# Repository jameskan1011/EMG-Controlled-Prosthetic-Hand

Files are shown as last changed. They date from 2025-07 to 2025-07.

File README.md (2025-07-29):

# EMG-Controlled Prosthetic Hand

This project features a **wireless prosthetic hand system** powered by EMG signal control.  
A wearable EMG device captures muscle activity and translates it into movement commands for a robotic hand.  
Force sensors on the robotic fingers detect contact pressure and send feedback wirelessly to activate a **vibration motor** on the glove.  
All communication is handled efficiently via the **ESP-NOW protocol** for real-time response.

---

## 🖐️ Prosthetic Hand

<p align="center">
  Prosthetic Hand
</p>

---

## 🧤 EMG Sensor Device

<p align="center">
  EMG Sensor Glove Front
  &nbsp;&nbsp;&nbsp;
  EMG Sensor Glove Back
</p>

---

## 📽️ Demonstration

<p align="center">
  <video src="https://github.com/user-attachments/assets/7f13d15d-7b53-4090-8c28-4c555c97ecc5" autoplay loop muted playsinline width="100"></video>
</p>

**Grasping Objects using Pinch and Power Grip**

<p align="center">
  Grasp Demo
</p>

---

## 🧠 Features
<h3 align="center">Sensor Feedback</h3>
<p align="left"><em>
Soft TPU material is layered above the fingertip and force sensor, allowing analog pressure values to be read when compressed.
</em></p>
<p align="center">
  
  &nbsp;&nbsp;&nbsp;
  
</p>

<p align="left"><em>
Each of the five servos is responsible for controlling an individual finger on the prosthetic hand, enabling coordinated grasping movements.
</em></p>
<p align="center">
  
</p>

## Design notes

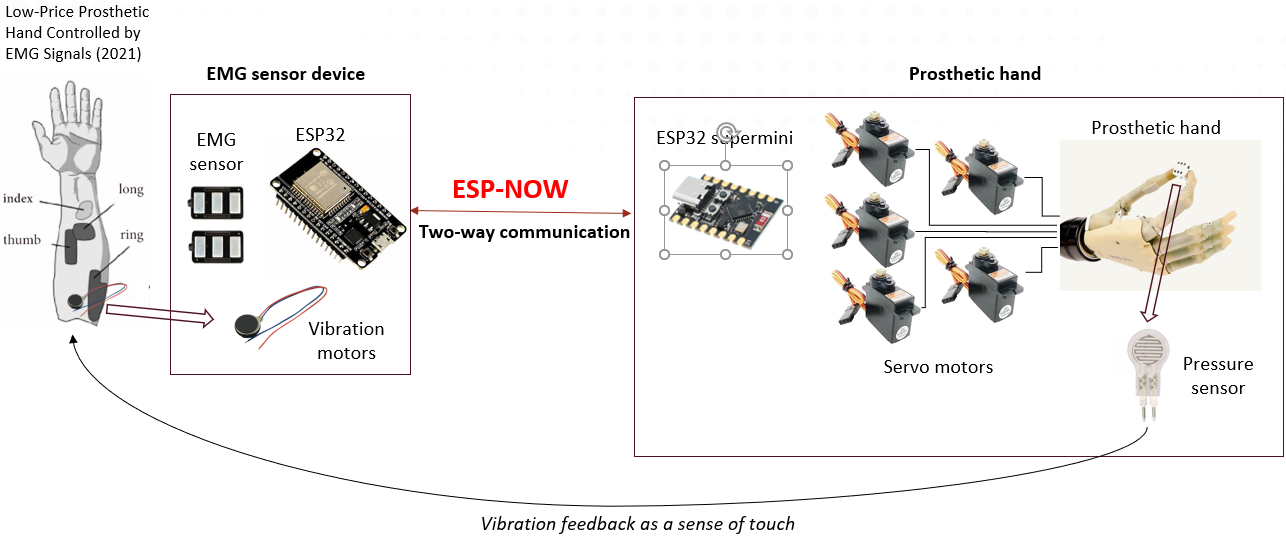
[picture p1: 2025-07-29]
Circuit/System.png

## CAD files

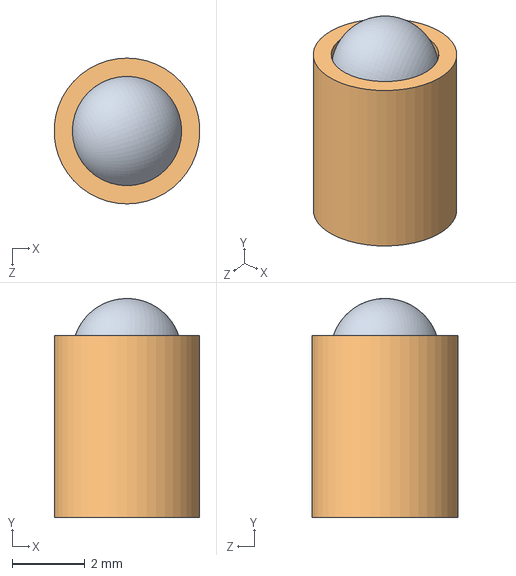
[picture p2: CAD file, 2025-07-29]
3D model/plunger/plunger.SLDASM
3.99 x 6.01 x 4.00 mm
bearing
socket

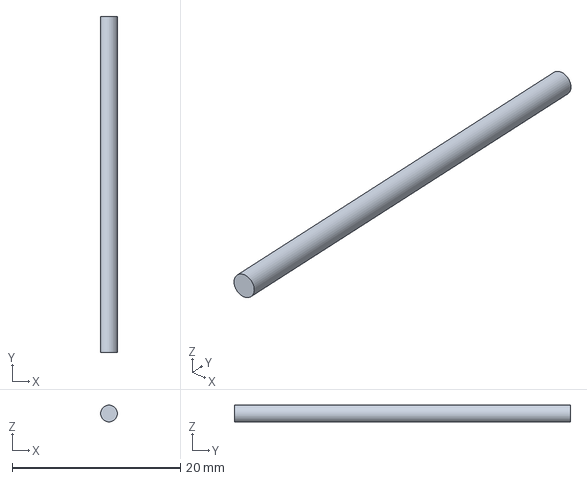
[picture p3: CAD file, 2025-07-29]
3D model/2mm joint.3MF
2.00 x 40.0 x 2.00 mm

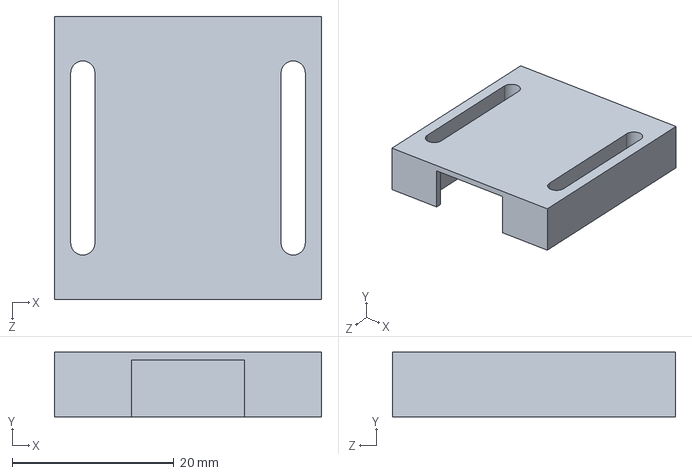
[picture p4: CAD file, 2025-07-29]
3D model/ESP32_enclosure/EMGsensor_cover.SLDPRT
33.0 x 8.00 x 35.0 mm

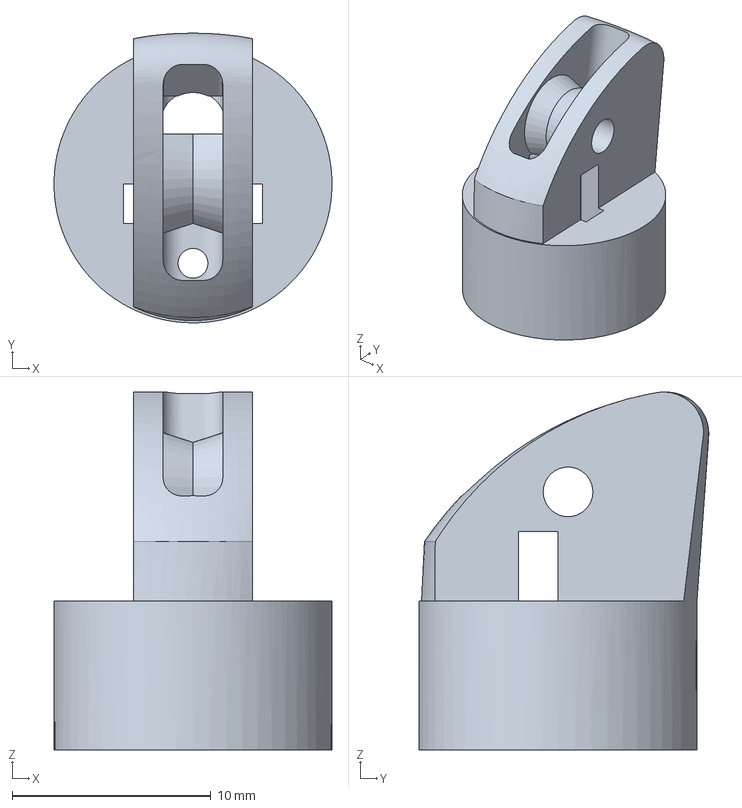
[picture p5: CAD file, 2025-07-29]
3D model/Index/bambu/index2_V4(reduce friction).3MF
14.0 x 14.6 x 18.0 mm

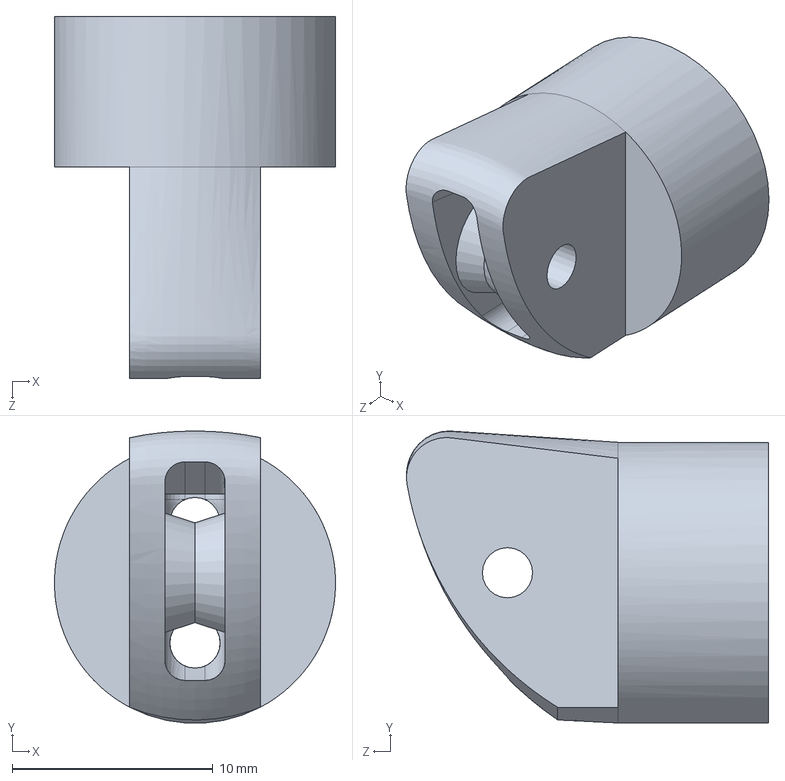
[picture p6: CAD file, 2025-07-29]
3D model/Index/index2.SLDPRT
14.0 x 14.5 x 18.0 mm

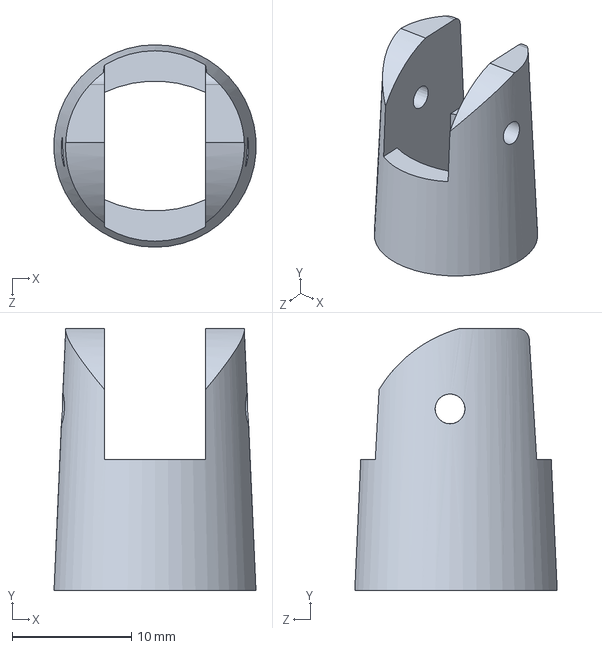
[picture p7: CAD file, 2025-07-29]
3D model/middle/middle3.SLDPRT
17.0 x 22.0 x 17.0 mm

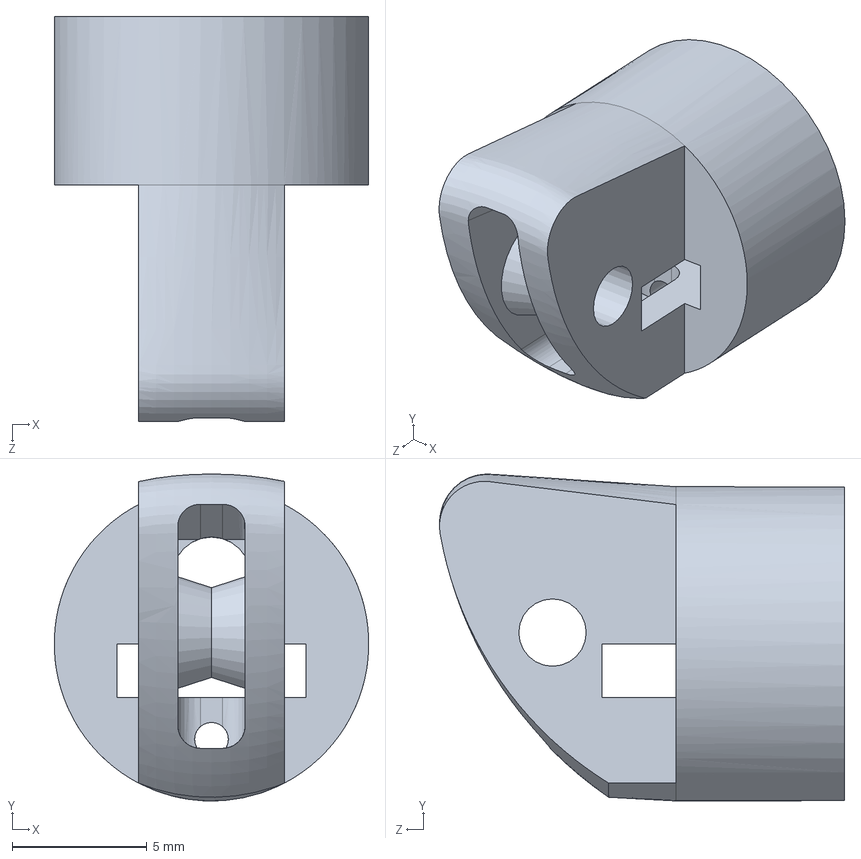
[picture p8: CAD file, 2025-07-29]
3D model/pinky/pinky2.SLDPRT
11.7 x 12.1 x 15.0 mm

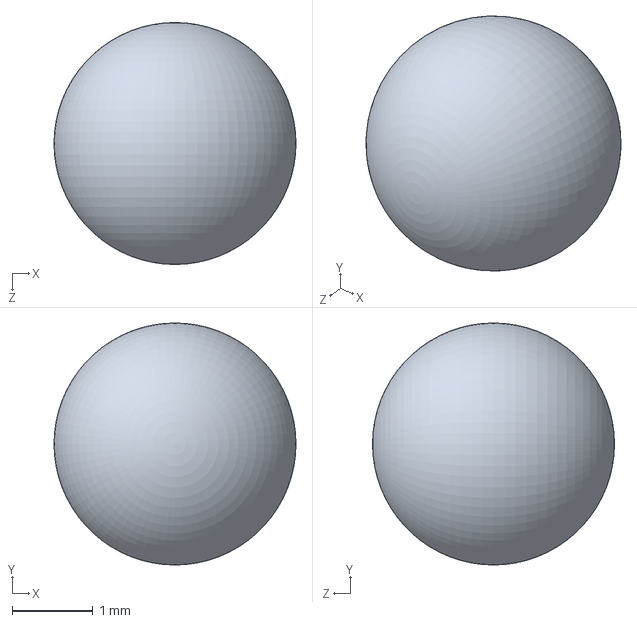
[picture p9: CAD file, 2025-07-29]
3D model/plunger/bearing.SLDPRT
3.00 x 3.00 x 3.00 mm

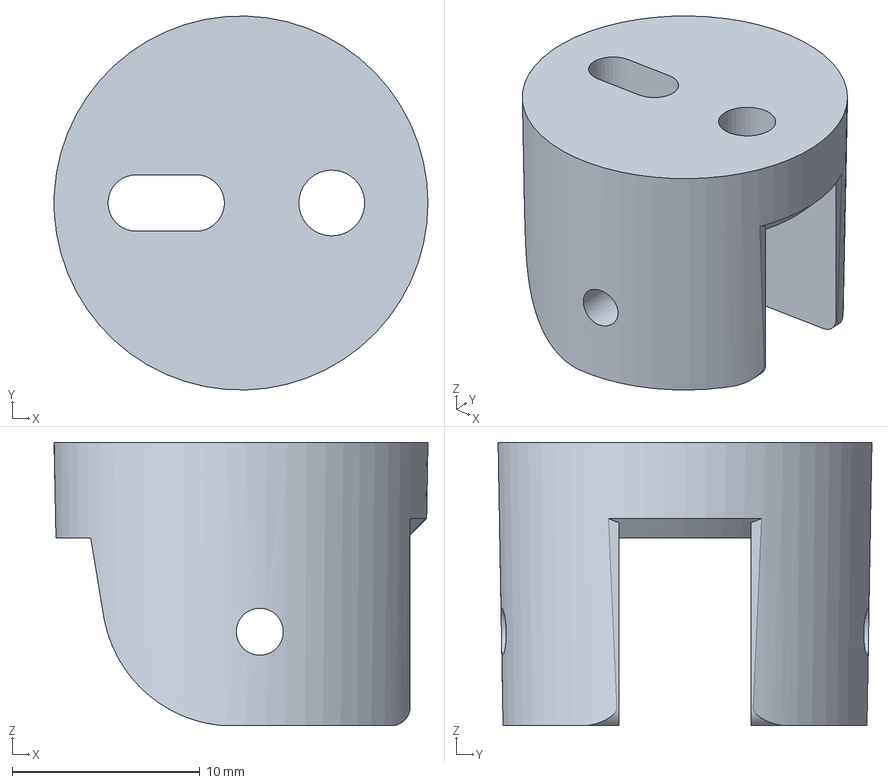
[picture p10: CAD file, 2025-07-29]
3D model/thumb/bambu/thump3.3MF
19.9 x 19.9 x 15.1 mm

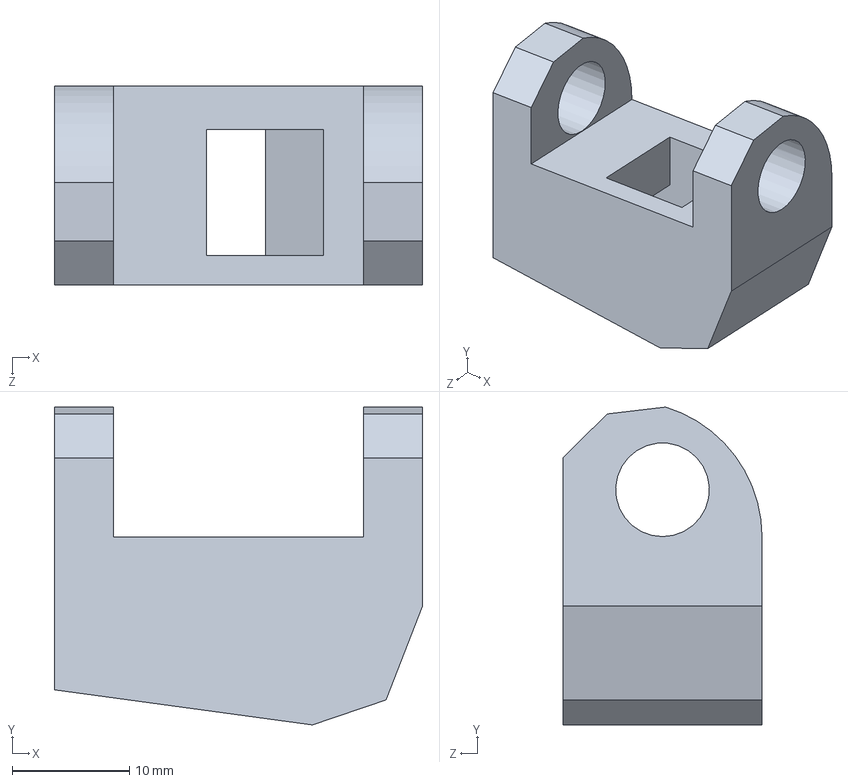
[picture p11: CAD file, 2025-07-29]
3D model/thumb/thump6_v2.SLDPRT
31.4 x 27.1 x 17.0 mm

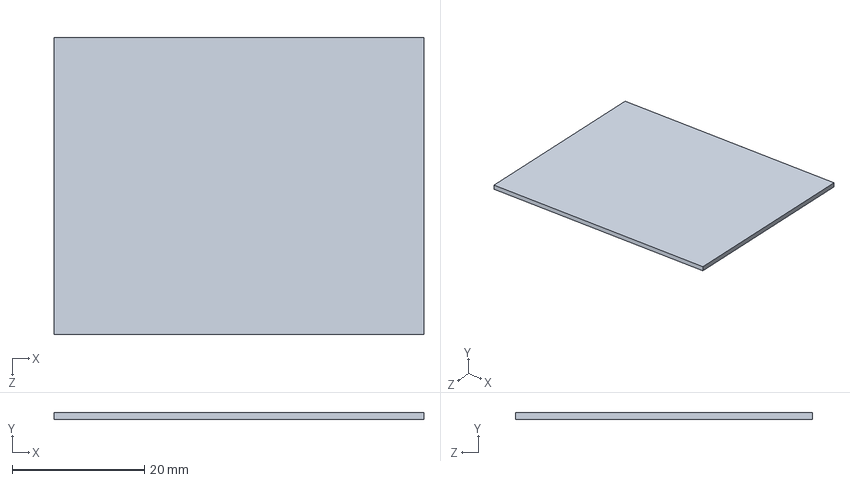
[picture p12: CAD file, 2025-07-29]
3D model/ESP32_enclosure/ESP32_enclosureLid.SLDPRT
56.0 x 1.00 x 45.0 mm

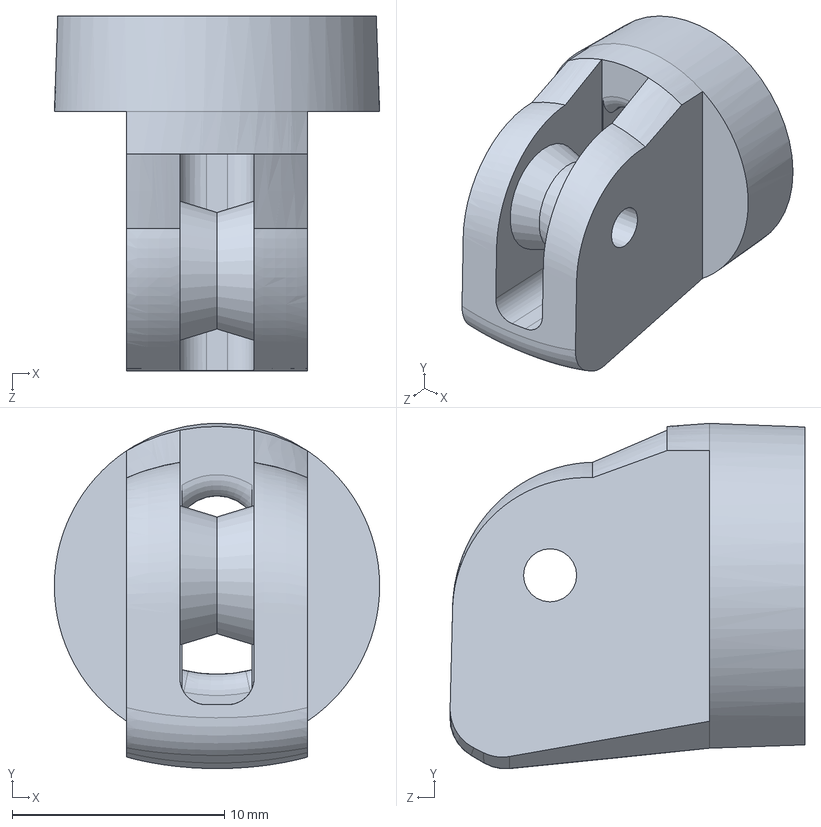
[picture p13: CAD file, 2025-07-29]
3D model/middle/middle5.SLDPRT
15.3 x 16.3 x 16.7 mm

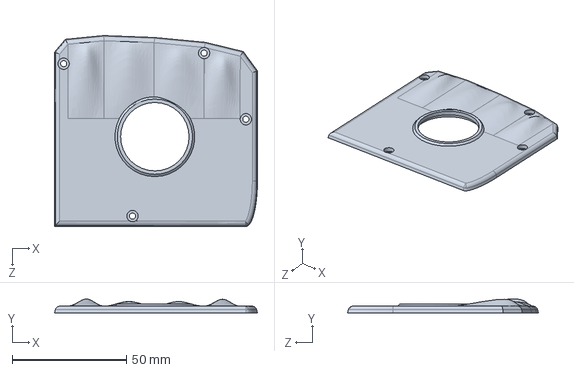
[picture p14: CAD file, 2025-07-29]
3D model/palm_bottom.SLDPRT
89.0 x 6.15 x 83.7 mm

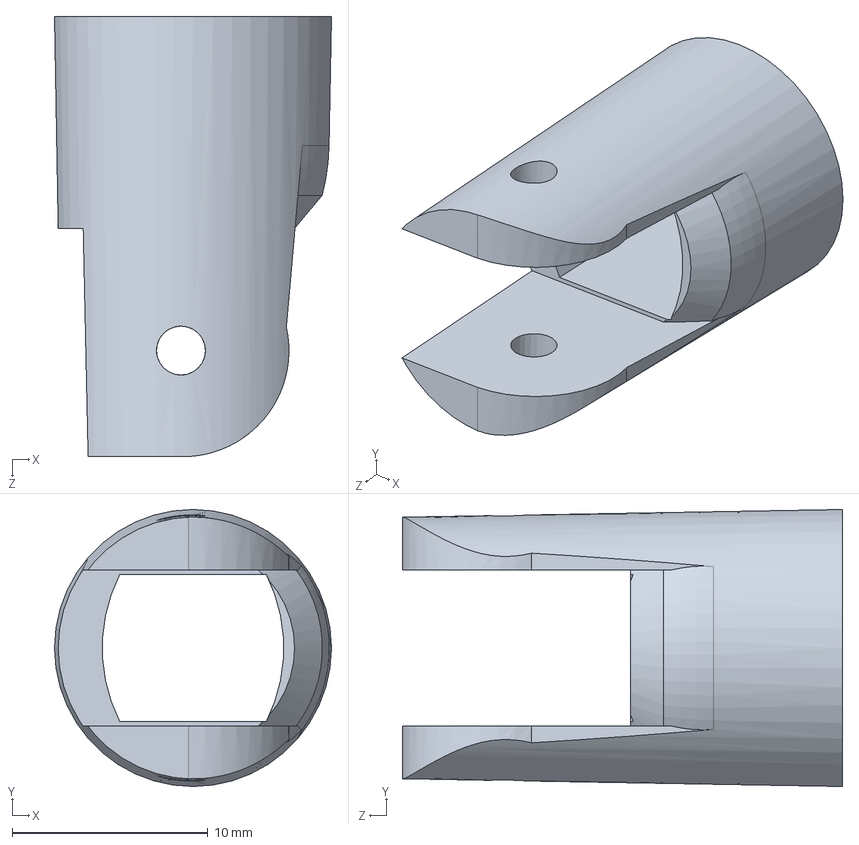
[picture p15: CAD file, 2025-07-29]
3D model/pinky/pinky4.SLDPRT
14.2 x 14.2 x 22.5 mm

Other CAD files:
3D model/Index/bambu/index2_V3.STEP
3D model/Index/index2_V4(reduce friction).SLDPRT
3D model/plunger/socket.SLDPRT
3D model/thumb/bambu/Thump1.3MF
3D model/2051_servo_tower-pro-sg90.pk2.SLDPRT
3D model/ESP32_enclosure/EMGsensor_cover.3MF
3D model/ESP32_enclosure/ESP32_enclosure.3MF
3D model/ESP32_enclosure/ESP32_enclosure.SLDPRT
3D model/ESP32_enclosure/ESP32_enclosureLid.3MF
3D model/Index/bambu/index1.3MF
3D model/Index/bambu/index1.gcode.3mf
3D model/Index/bambu/index1_TPU.3MF
3D model/Index/bambu/index1_TPU_V2.3MF
3D model/Index/bambu/index1_modifiled.3MF
3D model/Index/bambu/index1_modifiled.gcode.3mf
3D model/Index/bambu/index2.3MF
3D model/Index/bambu/index2_V2.3MF
3D model/Index/bambu/index2_V3.3mf
3D model/Index/bambu/index3.3MF
3D model/Index/bambu/index4.3MF
3D model/Index/bambu/index5.3MF
3D model/Index/bambu/index6.3MF
3D model/Index/bambu/index_all.gcode.3mf
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

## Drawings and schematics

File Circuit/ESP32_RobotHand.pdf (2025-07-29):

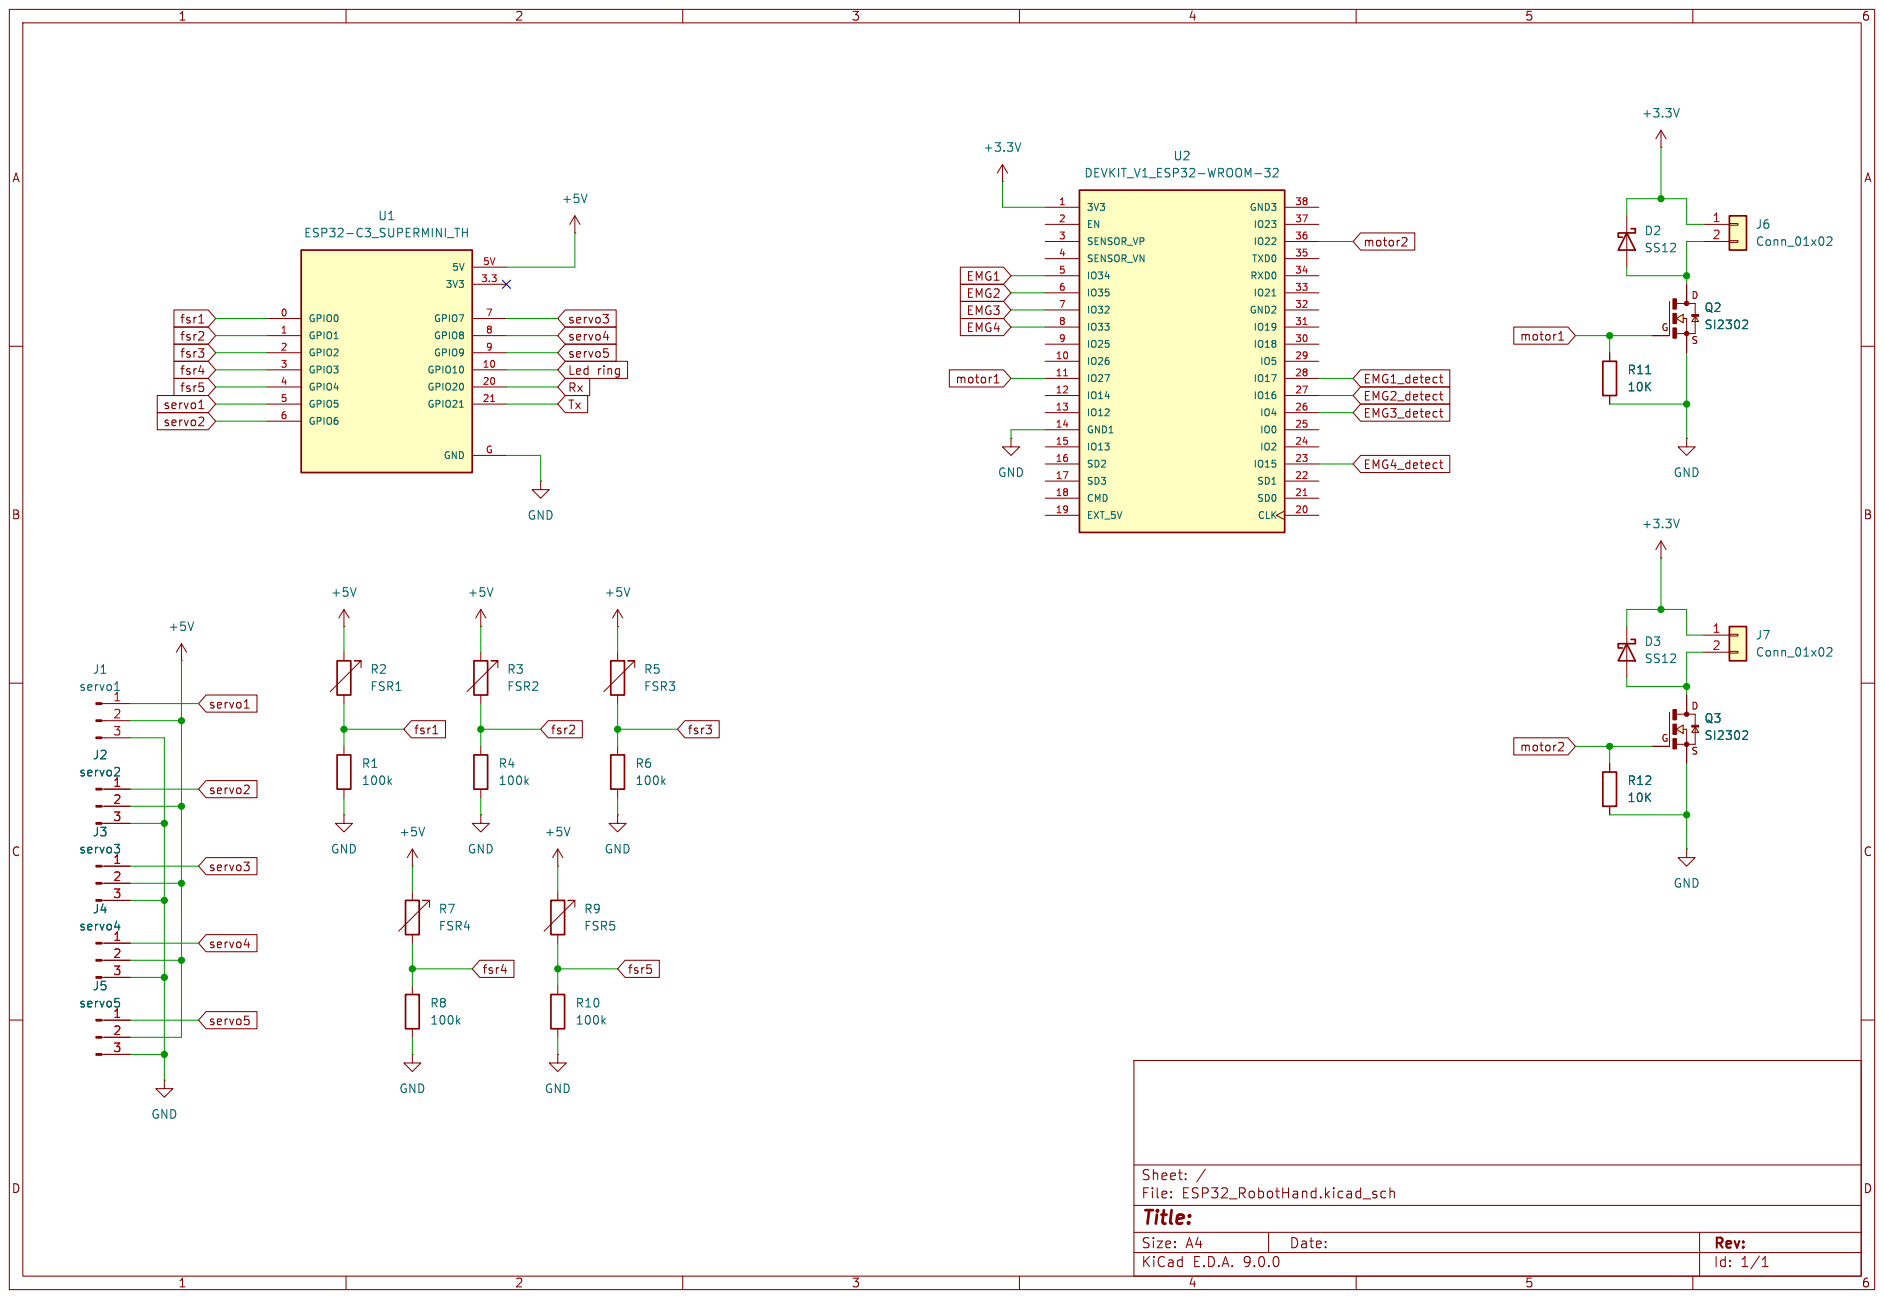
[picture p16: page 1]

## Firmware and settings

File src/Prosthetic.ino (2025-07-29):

#include <esp_now.h>
#include <WiFi.h>

#define SAMPLE_RATE 1000

#define INPUT_PIN_1 34
#define INPUT_PIN_2 35

#define DETECT_PIN_1 17
#define DETECT_PIN_2 16

#define MOTOR_PIN 27

#define BUFFER_SIZE 128
#define NUM_SERVOS 5

uint8_t servoAngles[NUM_SERVOS] = {180, 180, 180, 180, 180};
const int thresholds[2] = {20, 20};  // Sensor 1 and Sensor 2

int circular_buffer[2][BUFFER_SIZE];
int data_index[2] = {0};
int sum[2] = {0};

bool motorFlag = false;

uint8_t receiverMAC[] = {0xDC, 0x06, 0x75, 0x67, 0x62, 0xB8};  // Replace with your receiver MAC
esp_now_peer_info_t peerInfo;

struct FilterState {
  float z1[4] = {0}, z2[4] = {0};
};
FilterState filterStates[2];  // Only two sensors

void OnDataRecv(const esp_now_recv_info *info, const uint8_t *data, int len) {
  if (len == sizeof(bool)) {
    motorFlag = *data;
    digitalWrite(MOTOR_PIN, motorFlag ? HIGH : LOW);
  }
}

void setup() {
  Serial.begin(115200);
  WiFi.mode(WIFI_STA);

  pinMode(MOTOR_PIN, OUTPUT);
  digitalWrite(MOTOR_PIN, LOW);

  pinMode(DETECT_PIN_1, INPUT);
  pinMode(DETECT_PIN_2, INPUT);

  analogReadResolution(10);

  if (esp_now_init() != ESP_OK) {
    Serial.println("ESP-NOW init failed");
    return;
  }

  memcpy(peerInfo.peer_addr, receiverMAC, 6);
  peerInfo.channel = 0;
  peerInfo.encrypt = false;

  if (esp_now_add_peer(&peerInfo) != ESP_OK) {
    Serial.println("Failed to add peer");
    return;
  }

  esp_now_register_recv_cb(OnDataRecv);
}

void loop() {
  static unsigned long lastMicros = 0;
  unsigned long currentMicros = micros();

  if (currentMicros - lastMicros >= 1000000 / SAMPLE_RATE) {
    lastMicros = currentMicros;

    int value1 = readSensor(INPUT_PIN_1, DETECT_PIN_1, thresholds[0], 0);
    int value2 = readSensor(INPUT_PIN_2, DETECT_PIN_2, thresholds[1], 1);
    //Serial.print(value1);
    //Serial.println(value2);

    if (value1 >= thresholds[0]) {
      // Sensor 1 active → move all 5 servos
      for (int i = 0; i < NUM_SERVOS; i++) {
        servoAngles[i] = 0;
      }
    } else if (value2 >= thresholds[1]) {
      // Sensor 2 active → move servo 0 and 1
      servoAngles[0] = 0;
      servoAngles[1] = 0;
      for (int i = 2; i < NUM_SERVOS; i++) {
        servoAngles[i] = 180;
      }
    } else {
      // No trigger → default positions
      for (int i = 0; i < NUM_SERVOS; i++) {
        servoAngles[i] = 180;
      }
    }

    esp_now_send(receiverMAC, (uint8_t *)servoAngles, sizeof(servoAngles));

    Serial.print("[");
    for (int i = 0; i < NUM_SERVOS; i++) {
      Serial.print(servoAngles[i]);
      if (i < NUM_SERVOS - 1) Serial.print(" ");
    }
    Serial.println("]");
  }
}

int readSensor(int inputPin, int detectPin, int threshold, int index) {
  if (digitalRead(detectPin) == HIGH) {
    int raw = analogRead(inputPin);
    int filtered = Filter(raw, filterStates[index]);
    int envelope = getEnvelop(index, abs(filtered));
    return envelope;
  }
  return 0;
}

int getEnvelop(int index, int value) {
  sum[index] -= circular_buffer[index][data_index[index]];
  sum[index] += value;
  circular_buffer[index][data_index[index]] = value;
  data_index[index] = (data_index[index] + 1) % BUFFER_SIZE;
  return (sum[index] / BUFFER_SIZE) * 2;
}

float Filter(float input, FilterState &state) {
  float output = input;
  {
    float x = output - (-0.55195385 * state.z1[0]) - (0.60461714 * state.z2[0]);
    output = 0.00223489 * x + (0.00446978 * state.z1[0]) + (0.00223489 * state.z2[0]);
    state.z2[0] = state.z1[0];
    state.z1[0] = x;
  }
  {
    float x = output - (-0.86036562 * state.z1[1]) - (0.63511954 * state.z2[1]);
    output = 1.0 * x + (2.0 * state.z1[1]) + (1.0 * state.z2[1]);
    state.z2[1] = state.z1[1];
    state.z1[1] = x;
  }
  {
    float x = output - (-0.37367240 * state.z1[2]) - (0.81248708 * state.z2[2]);
    output = 1.0 * x + (-2.0 * state.z1[2]) + (1.0 * state.z2[2]);
    state.z2[2] = state.z1[2];
    state.z1[2] = x;
  }
  {
    float x = output - (-1.15601175 * state.z1[3]) - (0.84761589 * state.z2[3]);
    output = 1.0 * x + (-2.0 * state.z1[3]) + (1.0 * state.z2[3]);
    state.z2[3] = state.z1[3];
    state.z1[3] = x;
  }
  return output;
}

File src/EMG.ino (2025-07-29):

#include <esp_now.h>
#include <WiFi.h>
#include <ESP32Servo.h>

// MAC of sender device
uint8_t senderMAC[] = {0x58, 0xBF, 0x25, 0xA1, 0x44, 0x90};

// Pins
int servoPins[5] = {5, 6, 7, 8, 9};
#define FSR_PIN_1 0
#define FSR_PIN_2 1
#define FSR_PIN_3 2
#define FSR_PIN_4 3
#define FSR_PIN_5 4

Servo servos[5];

// Servo position control
uint8_t currentPositions[5] = {180, 180, 180, 180, 180};  // Initial
uint8_t targetPositions[5] = {90, 90, 90, 90, 90};   // Updated on receive
unsigned long lastUpdateTime = 0;
const unsigned long updateInterval = 5; // ms between servo steps

bool motorFlag = false;
esp_now_peer_info_t peerInfo;

// Callback: when data received
void OnDataRecv(const esp_now_recv_info *info, const uint8_t *data, int len) {
  if (len == sizeof(targetPositions)) {  // Fix: match real array
    memcpy(targetPositions, data, sizeof(targetPositions));  // Update targets

    Serial.print("[");
    for (int i = 0; i < 5; i++) {
      Serial.print(targetPositions[i]);
      if (i < 4) Serial.print(" ");
    }
    Serial.println("]");
  } else {
    Serial.println("Received data size mismatch!");
  }
}

void setup() {
  Serial.begin(115200);
  WiFi.mode(WIFI_STA);
  analogReadResolution(10);

  // Attach servos
  for (int i = 0; i < 5; i++) {
    servos[i].setPeriodHertz(50);
    servos[i].attach(servoPins[i], 500, 2400);
    servos[i].write(currentPositions[i]); // Set to initial position
  }

  // Initialize ESP-NOW
  if (esp_now_init() != ESP_OK) {
    Serial.println("ESP-NOW init failed");
    return;
  }

  memcpy(peerInfo.peer_addr, senderMAC, 6);
  peerInfo.channel = 0;
  peerInfo.encrypt = false;

  if (esp_now_add_peer(&peerInfo) != ESP_OK) {
    Serial.println("Failed to add peer");
    return;
  }

  esp_now_register_recv_cb(OnDataRecv);
}

void loop() {
  unsigned long currentTime = millis();

  // Smooth servo movement
  if (currentTime - lastUpdateTime >= updateInterval) {
    lastUpdateTime = currentTime;

    for (int i = 0; i < 5; i++) {
      if (currentPositions[i] != targetPositions[i]) {
        currentPositions[i] += (currentPositions[i] < targetPositions[i]) ? 1 : -1;
        servos[i].write(currentPositions[i]);
      }
    }
  }

  // Read FSRs
  int fsr1 = analogRead(FSR_PIN_1);
  int fsr2 = analogRead(FSR_PIN_2);
  int fsr3 = analogRead(FSR_PIN_3);
  int fsr4 = analogRead(FSR_PIN_4);
  int fsr5 = analogRead(FSR_PIN_5);


  // Motor flag logic
  motorFlag = (fsr1 > 100 || fsr2 > 100 || fsr3 < 100 || fsr4 > 100 || fsr5 > 100);
  esp_now_send(senderMAC, (uint8_t *)&motorFlag, sizeof(motorFlag));

}
